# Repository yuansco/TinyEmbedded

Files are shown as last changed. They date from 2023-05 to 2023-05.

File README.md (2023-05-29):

# TinyEmbedded - F1C200s Embedded Linux Development Board

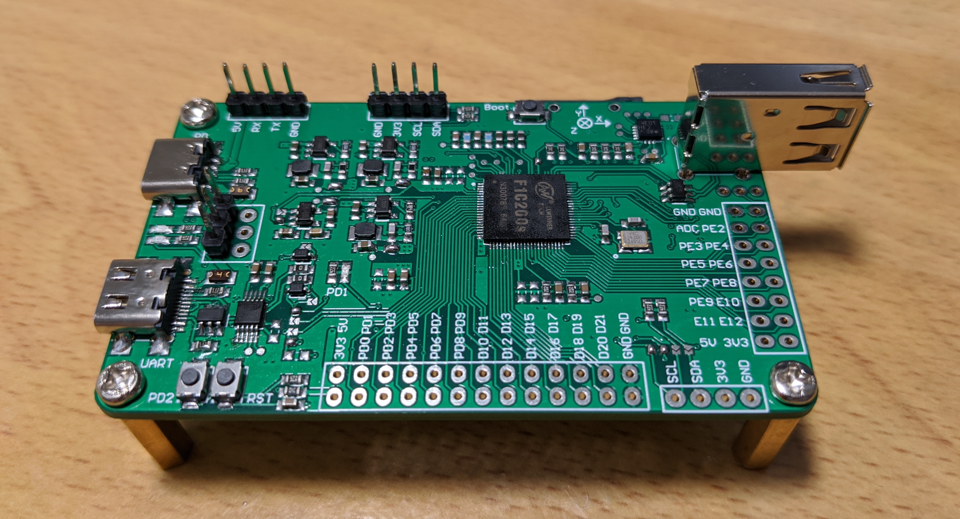
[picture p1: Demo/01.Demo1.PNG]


The TinyEmbedded is a low-cost embedded Linux development board that features an ARM9-based F1C200s microprocessor with an integrated USB-to-UART serial console. Here are some highlights of this development board:

 * F1C200s: An ARM9-based microprocessor with an integrated 64MB DRAM.

 * On-board USB-to-UART serial console.

 * On-board LIS3DH acceleration sensor.

 * SSD1306-based 128x64 OLED display module.

 * One USB Type-A port.

 * Three indicator LEDs for power status, UART data transmission, and user-defined purposes.

 * Three buttons for reset, boot mode selection, and user-defined purposes.

 * One MicroSD slot for storing the boot image.

 * 16MB Serial NOR Flash.

 * AT24C02: A 2KB EEPROM.

After downloading the image to the SD card and starting the system, you can open the COM port via USB to view the boot logs of U-Boot and the Linux kernel. Once the system boots to the root filesystem, the OLED module will display 'Hi F1C200s'.

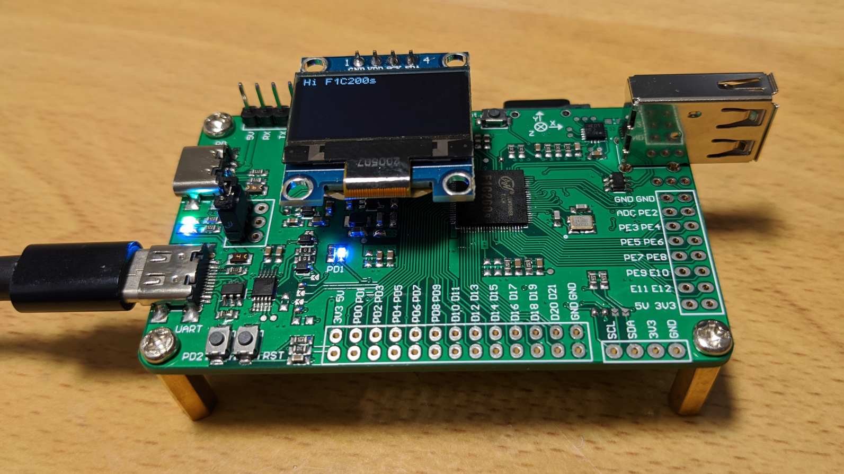
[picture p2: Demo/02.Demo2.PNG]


### Hardware Design

#### Block Diagram

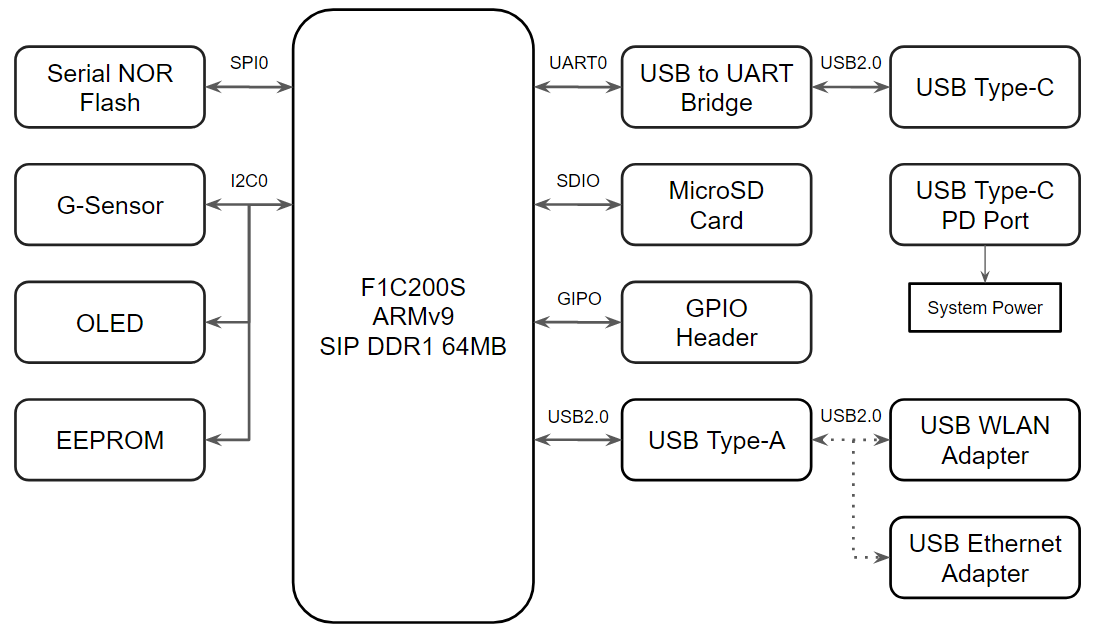
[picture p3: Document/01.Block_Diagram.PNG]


#### Power Tree

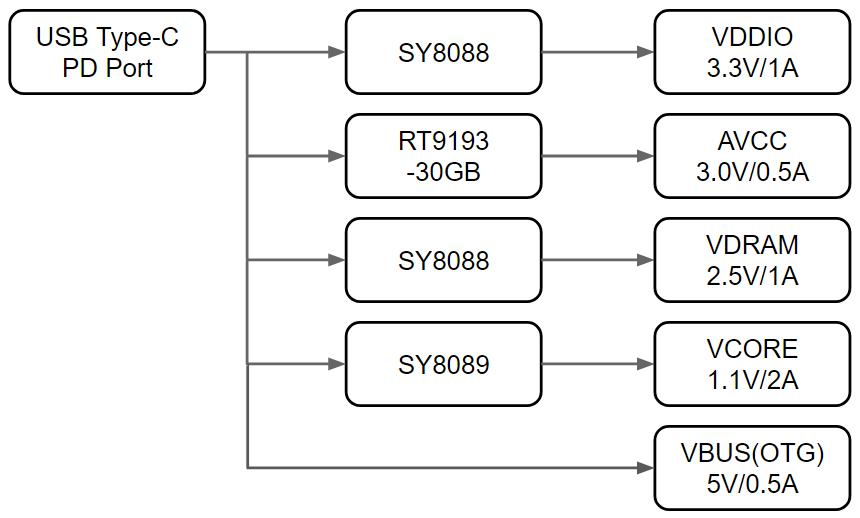
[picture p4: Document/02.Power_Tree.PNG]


#### 3D View

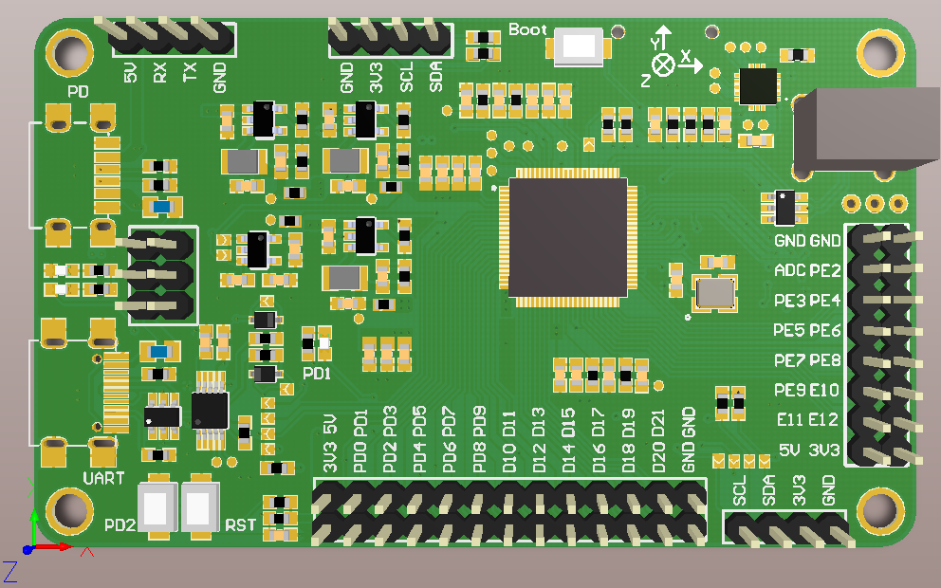
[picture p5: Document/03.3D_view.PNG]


#### Top View

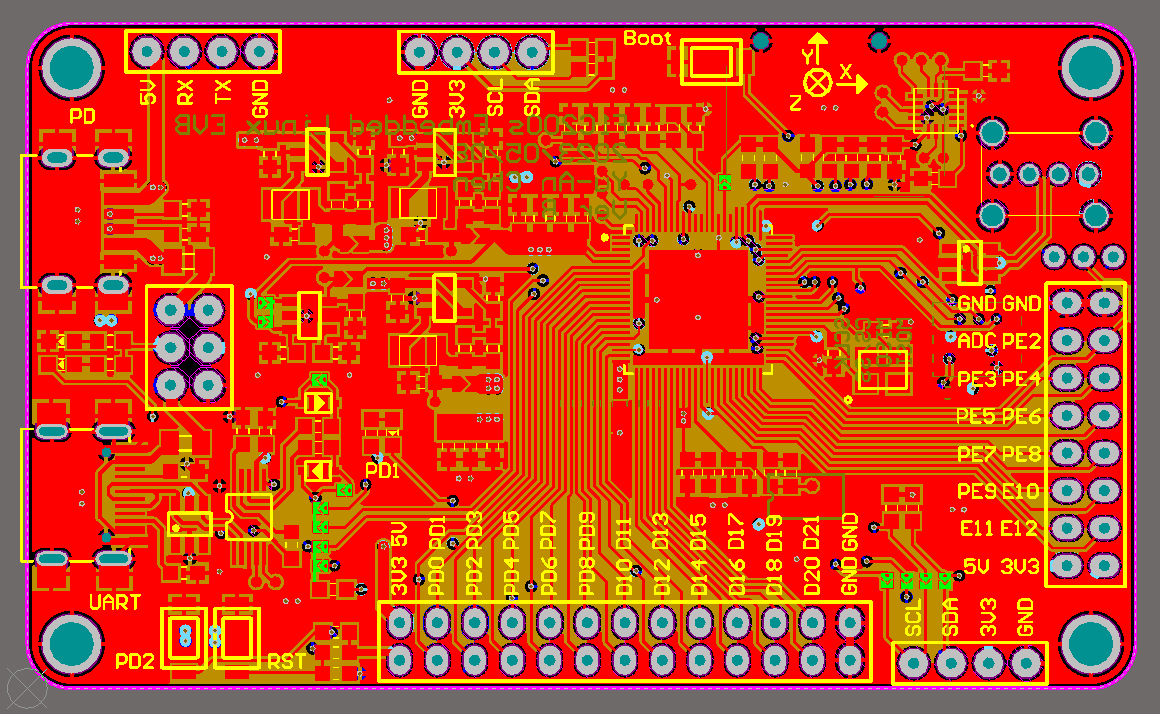
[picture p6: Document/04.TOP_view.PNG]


#### Download

Schematic: [PDF](https://github.com/yuansco/TinyEmbedded/blob/master/Document/TinyEmbedded_VerB.pdf)

BOM: [CSV](https://github.com/yuansco/TinyEmbedded/blob/master/Document/BOM.CSV)

Image: [IMG](https://github.com/yuansco/TinyEmbedded/blob/master/Images/sysimage-sdcard.img)

### Build an SD card image for booting

Install necessary packages:
``` shell
sudo apt install wget unzip build-essential git bc swig libncurses-dev libpython3-dev libssl-dev
sudo apt install python3-distutils
```
Download BSP (Buildroot-based BSP in another [repository](https://github.com/yuansco/buildroot-f1c200s)):
``` shell
git clone https://github.com/yuansco/buildroot-f1c200s.git
```
Apply defconfig and build image
``` shell
cd buildroot-tiny200
make tinyembedded_defconfig
make
```

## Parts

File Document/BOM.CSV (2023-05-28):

Bill of Material for
On 2023/5/28 at ¤W¤È 11:31:29
Comment | Pattern | Quantity | Components
*0.1uF,0603 | C0603 | 8 | C14, C15, C24, C25, C26, C29, C30, C31
*1.5k£[,0603 | R0603 | 1 | R1
*4.7k£[,0603 | R0603 | 1 | R34
*47k£[,0603 | R0603 | 2 | R11, R12
0.1uF,0603 | C0603 | 10 | C1, C2, C5, C7, C16, C27, C32, C39, C40, C41
0£[,0603 | R0603 | 3 | R32, R33, R35
10k£[,0603 | R0603 | 7 | R4, R5, R6, R7, R8, R15, R24
10uF,0603 | C0603 | 10 | C6, C8, C10, C18, C20, C21, C23, C34, C35, C36
150K£[,0603 | R0603 | 3 | R17, R18, R21
15pF,0603 | C0603 | 3 | C9, C19, C22
180K£[,0603 | R0603 | 1 | R20
1N5819 | SOD-323 | 2 | D1, D2
1uF,0603 | C0603 | 7 | C11, C12, C17, C28, C33, C37, C38
2.2uH | IND_252010_SMD | 3 | L1, L2, L3
200k£[,0603 | R0603 | 2 | R22, R23
20pF,0603 | C0603 | 2 | C42, C43
22nF,0603 | C0603 | 1 | C13
24MHz | XTAL_SMD_3225 | 1 | X2
2k£[,0603 | R0603 | 2 | R25, R26
4.7k£[,0603 | R0603 | 8 | R13, R14, R27, R28, R29, R30, R31, R36
470K£[,0603 | R0603 | 1 | R19
5.1k£[,0603 | R0603 | 4 | R2, R3, R9, R10
5V,1.5A,0805 | F0805 | 1 | F1
5V,3A,0805 | F0805 | 1 | F2
680K£[,0603 | R0603 | 1 | R16
AT24C02 | SOP8 | 1 | U5
blue,0603 | LED0603 | 1 | LD2
CH340E | MSOP-10 | 1 | U1
F1C200S | MQFN_10_10_v3 | 1 | U11
FFC_FPC_6P | FPC_1MM_6P | 1 | P11
green,0603 | LED0603 | 1 | LD1
Header_13x2 | Header_13x2 | 1 | P7
Header_3 | Header_3_2mm | 1 | P10
Header_3 | HEADER_3_2MM_SMD | 1 | P12
Header_3x2 | HEADER_3x2 | 1 | P2
Header_4 | Header_4 | 2 | P1, P9
Header_4 | HEADER_4_SMD | 1 | P6
Header_8*2 | Header_8*2 | 1 | P8
Jump_2 | Jp_small | 15 | J2, J3, J4, J5, J7, J8, J9, J10, J11, J12, J13, J18, J19, J20, J21
Jump_2 | power_jump | 4 | J14, J15, J16, J17
LIS3DH | LGA-16 | 1 | U4
MicroSD | MicroSD | 1 | P4
OLED_128x64 | Header_4 | 1 | P5
RT9193-30GB | SOT-23-5p | 1 | U8
SPI Flash | WSON8 | 1 | U6
SRV05-4 | SOT23-6 | 2 | U2, U3
SW_2P | SW_2P_4 | 3 | B1, BOOT, RST1
SY8088 | SOT-23-5p | 2 | U7, U10
SY8089 | SOT-23-5p | 1 | U9
TP | TP | 24 | TP1, TP2, TP3, TP4, TP5, TP6, TP7, TP8, TP9, TP10, TP11, TP12, TP13, TP14, TP15, TP16, TP17, TP18, TP19, TP20, TP21, TP22, TP23, TP24
TypeC_F | Type-C_16P_F_0.5_BOTH | 1 | J1 | Female SMD Connector
TypeC_F | Type-C_6P_F_BOTH | 1 | J6 | Female SMD Connector
USB_port | USB-A-female-90 | 1 | P3
white,0603 | LED0603 | 1 | LD3

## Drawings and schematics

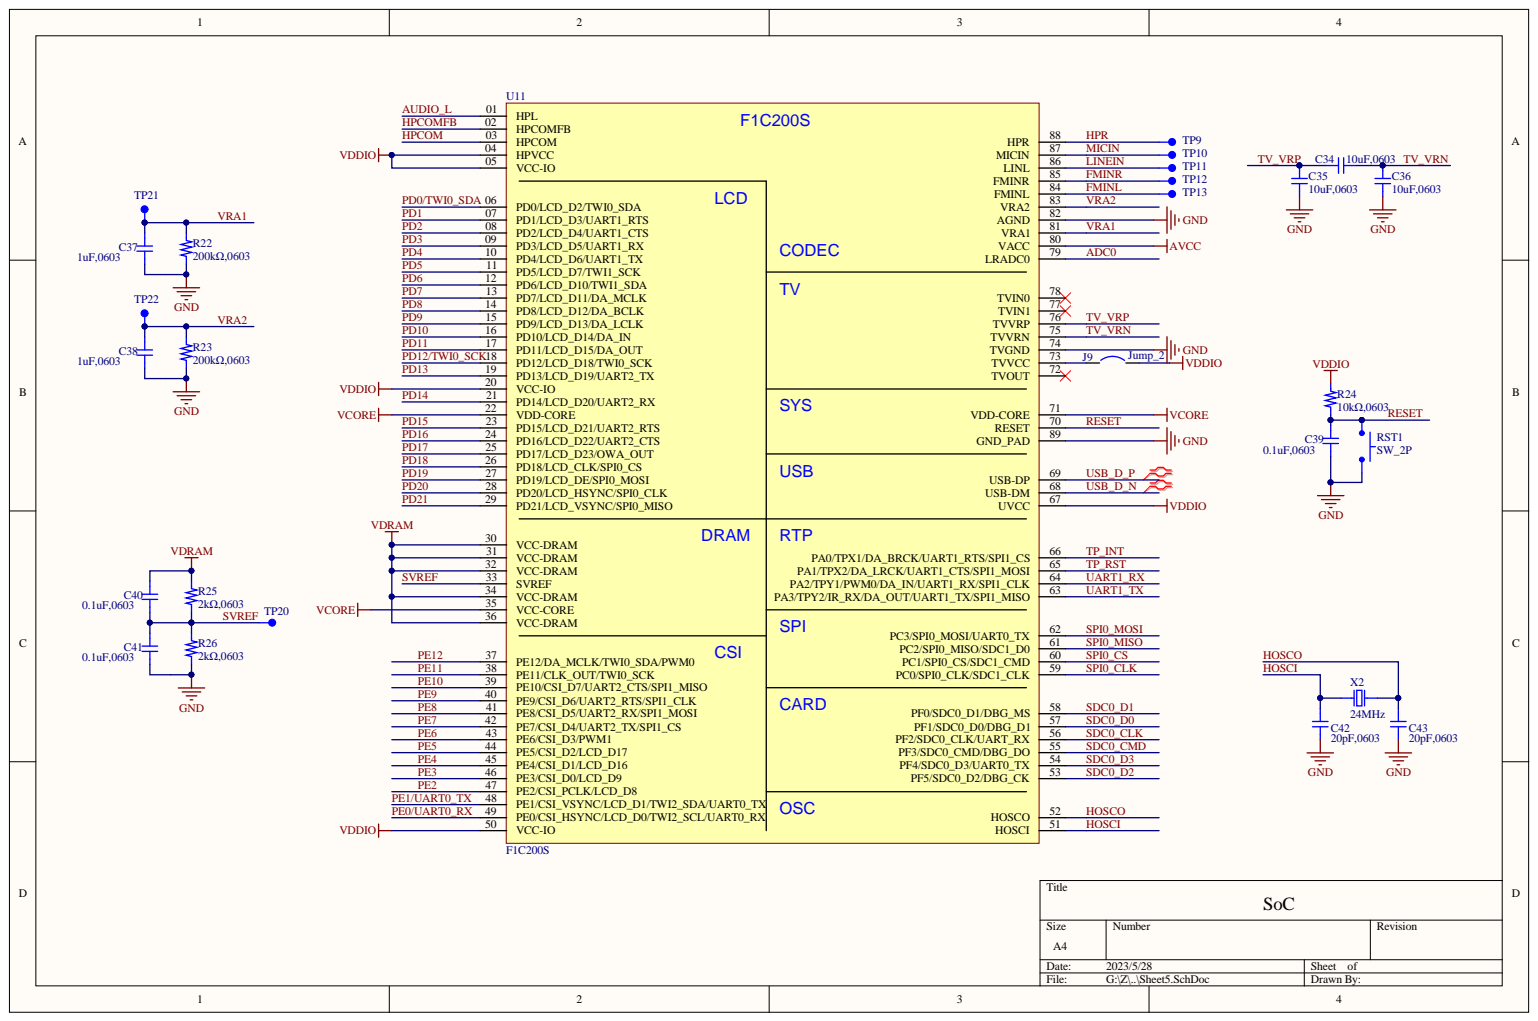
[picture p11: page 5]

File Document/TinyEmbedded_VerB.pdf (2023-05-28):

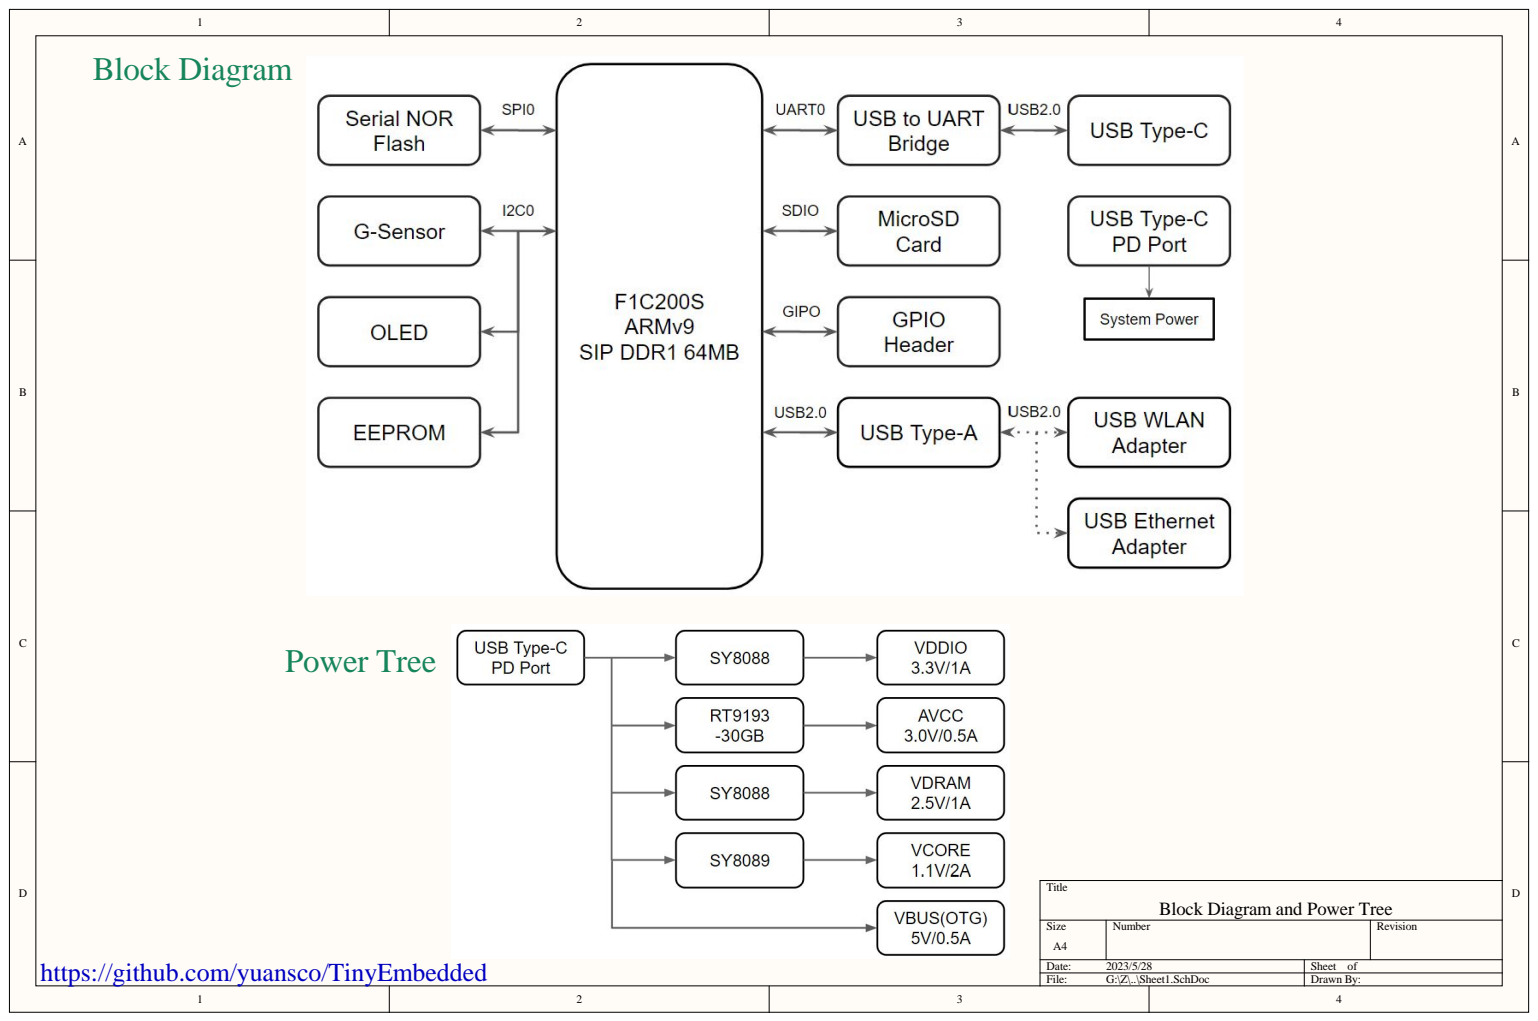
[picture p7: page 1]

Block Diagram and Power Tree

https://github.com/yuansco/TinyEmbedded

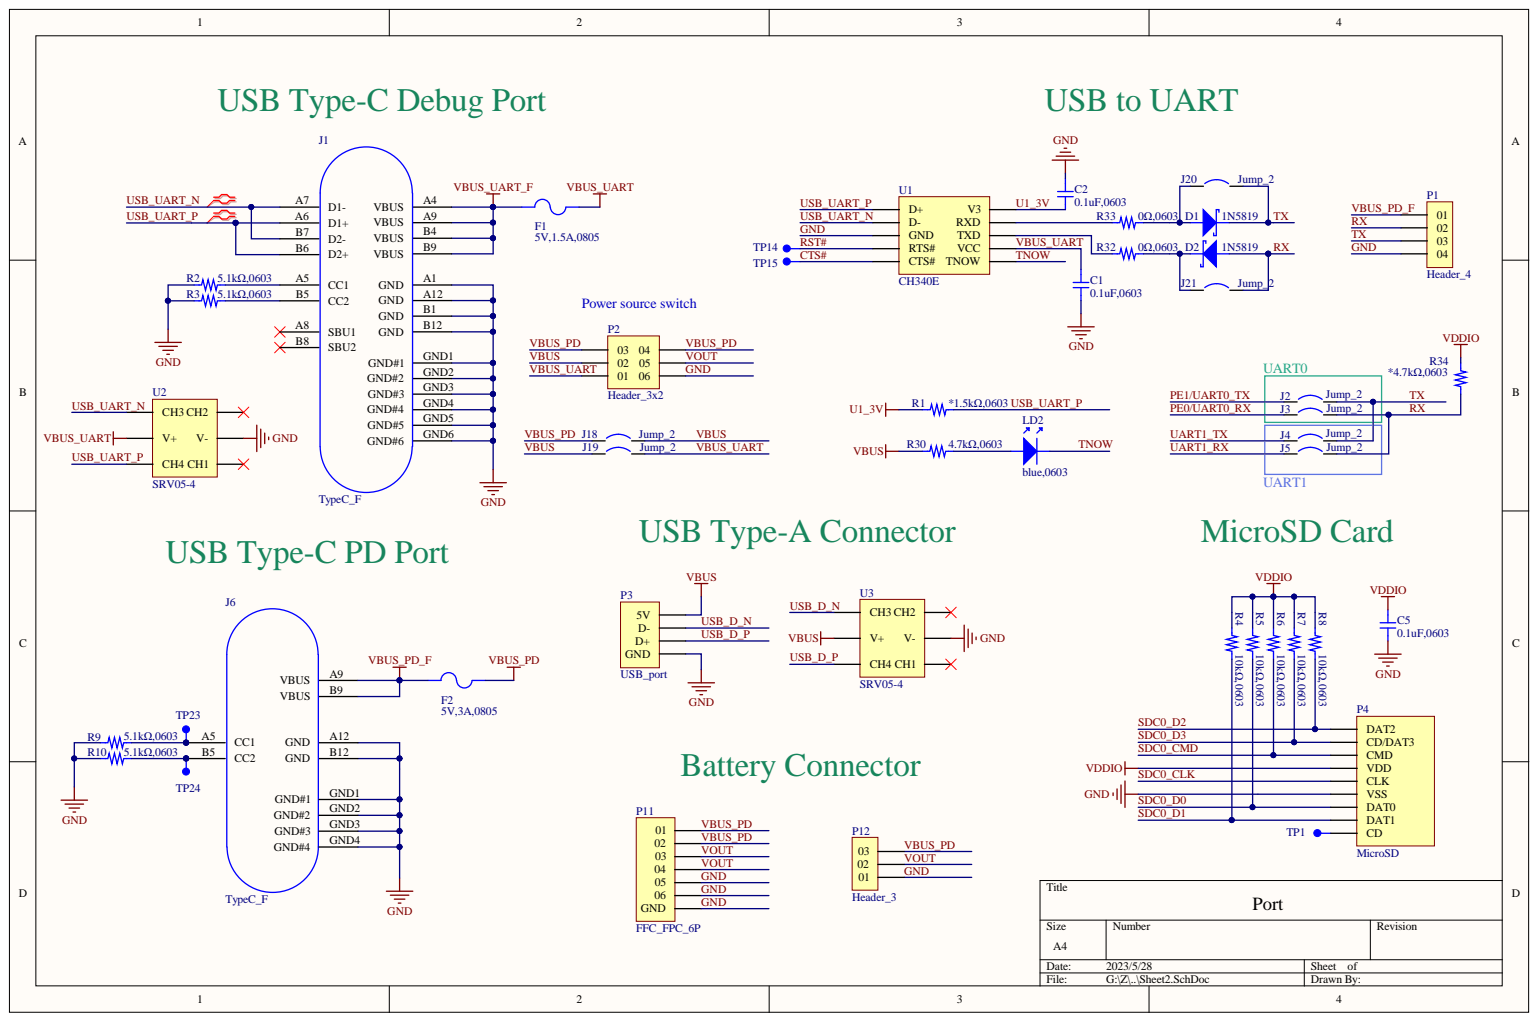
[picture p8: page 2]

USB Type-C Debug Port

USB Type-C PD Port

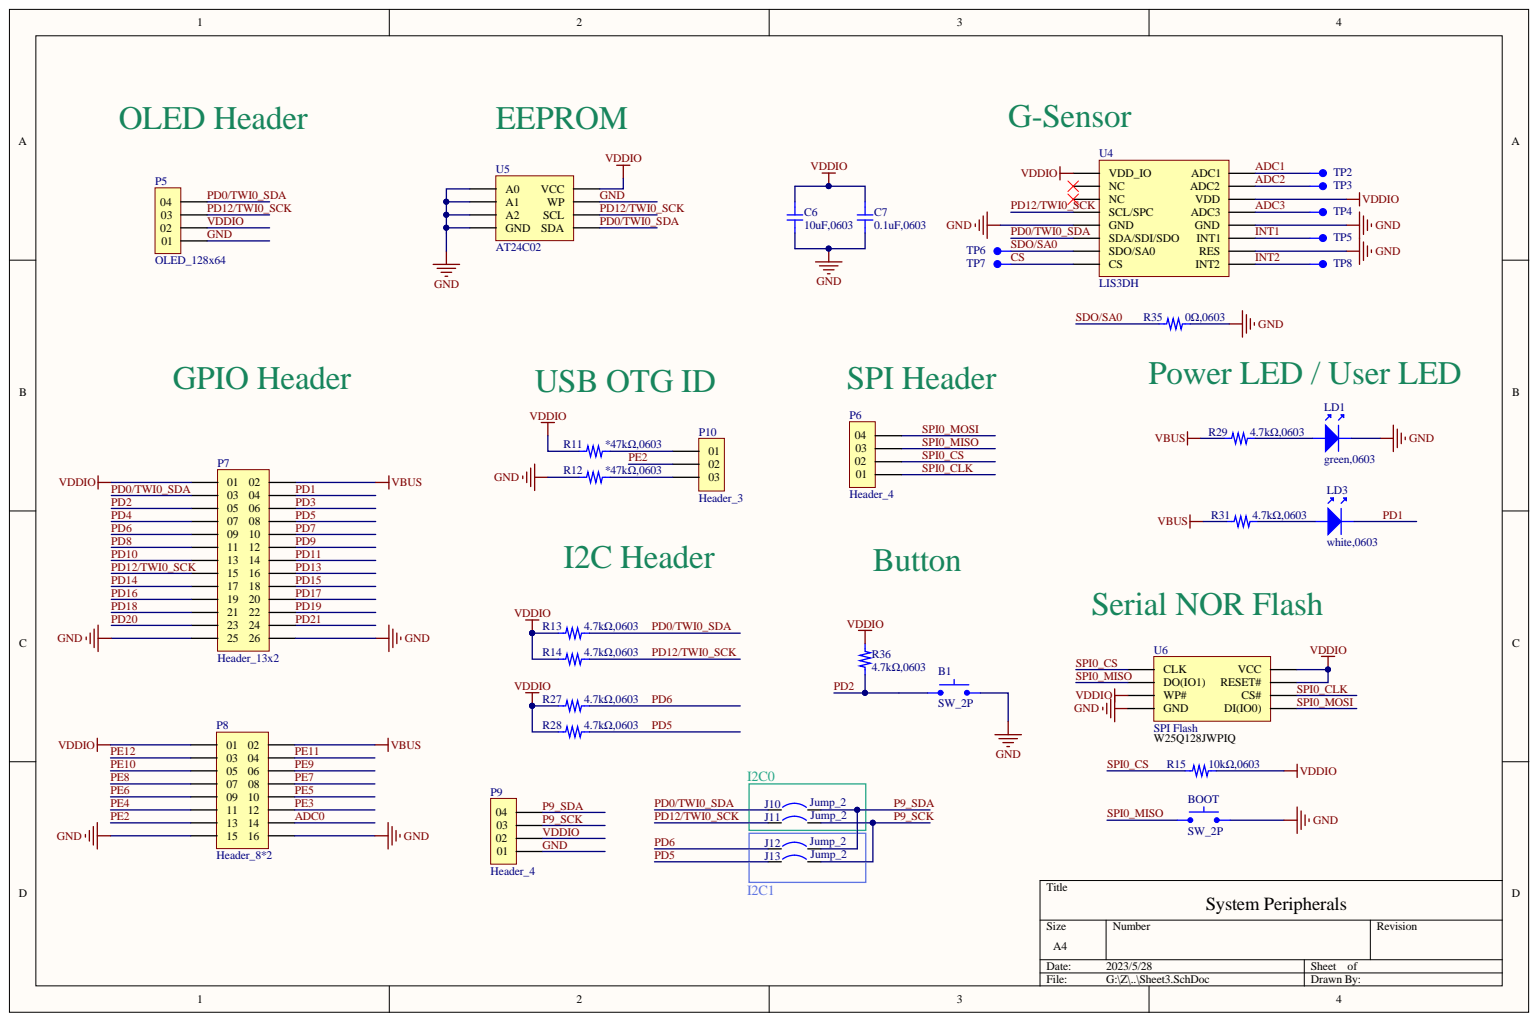
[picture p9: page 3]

Power LED / User LED LD1

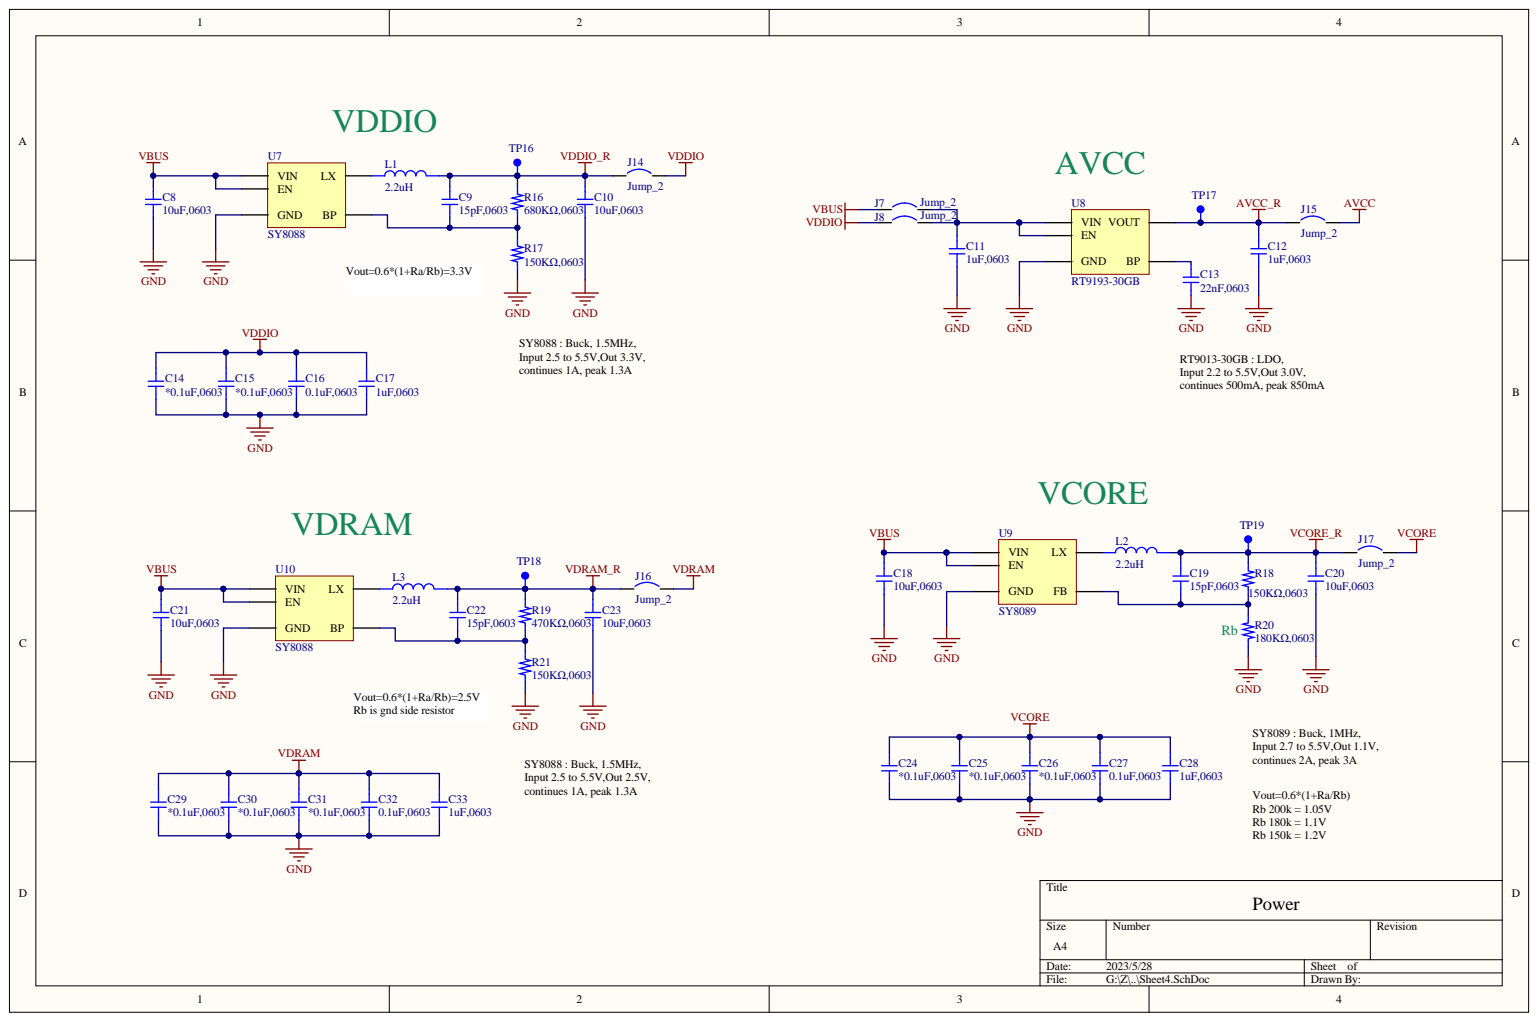
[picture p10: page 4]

Vout=0.6*(1+Ra/Rb)=2.5V
Rb is gnd side resistor
